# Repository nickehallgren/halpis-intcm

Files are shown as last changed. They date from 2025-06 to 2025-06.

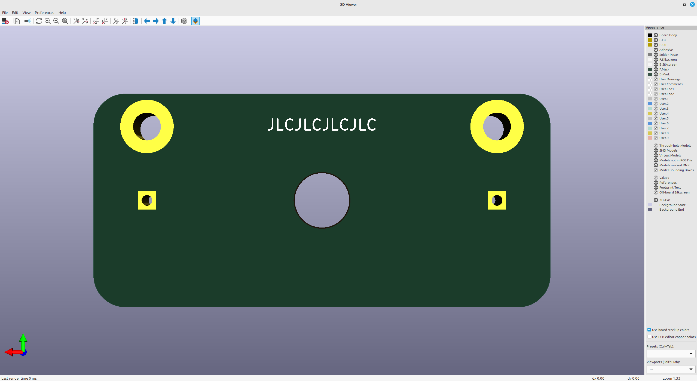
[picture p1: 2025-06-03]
hw/bp/images/2024_7_battery_connector_v1_1_back.png

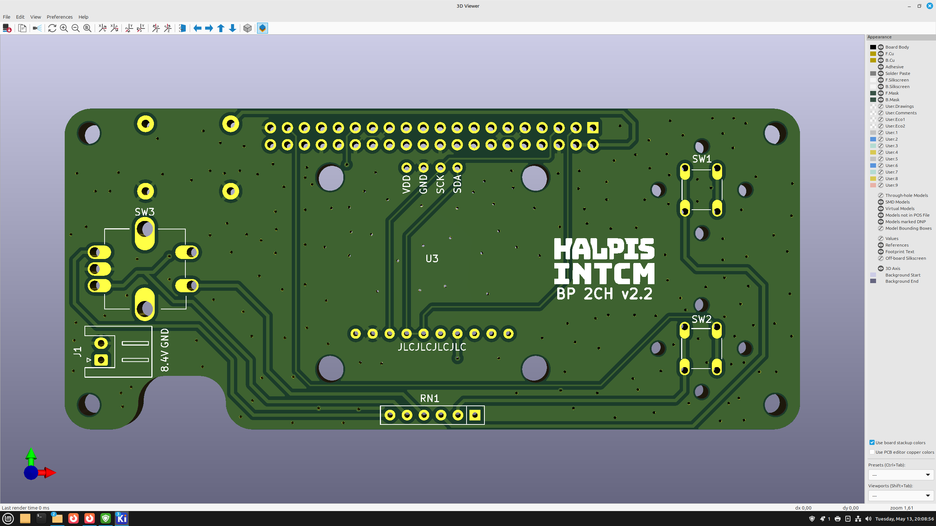
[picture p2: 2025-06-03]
hw/bp/images/2024_19_rpi3a_bp_v2_2_front.png

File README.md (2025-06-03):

HALPIS INTCM

A DIY Intercom System Built on Raspberry Pi, Custom Hardware, and Mumble

    ⚠️ Disclaimer
    This repository is for archival purposes only.
    I will not be updating the code or providing support.
    That said — feel free to fork it, explore it, and adapt it to your needs!

🎙️ Overview

HALPIS INTCM is a fully custom-built intercom system originally developed as a project at Arcada University of Applied Sciences. The project began over 6 years ago — [watch the original prototype](https://youtu.be/14hbYhLjQ8Y) — and has evolved through hundreds of hours of spare-time development.

At its core, HALPIS INTCM uses Raspberry Pi hardware with deeply integrated software built around Mumble, a low-latency, open-source voice chat system. It's designed to provide stable and clear communication in environments like workshops, multi-room setups, and media production spaces.

🔧 Features

    Custom-designed PCBs (Gerbers included)

    Ready for SMD component assembly

    3D-printable STL files for enclosures

    Raspberry Pi-based nodes for flexible deployment

    Integrated with Mumble for high-quality voice transmission

    90% of the software has been rewritten from scratch

📚 Background

The original version of HALPIS INTCM was successfully deployed in Arcada’s multi-camera workshops and served reliably for years. As time passed, both the software and hardware needed a full refresh.

This updated version is the result of:

    Rewriting nearly all the code (self-taught, so don’t expect perfection!)

    Learning KiCad and designing completely new PCBs

    Creating a more modular and maintainable system

    Spending many, many hours tinkering, testing, and refining

📦 What’s Included

    ✅ Full source code

    ✅ Hardware design (Gerbers, BOM)

    ✅ STL files for 3D-printed cases

    ✅ Configuration scripts and setup files

📺 Installation and setup Playlists on YouTube (Please watch the videos in sequence to fully understand the system before deciding whether it suits your needs.):

[Hardware playlist](https://www.youtube.com/playlist?list=PLlqbl5uwx39gumhSaHmBt5Q9jyUTHKmu8)

[Software playlist](https://www.youtube.com/playlist?list=PLlqbl5uwx39iHd4o0S4KNSksK1rH12pub)

This project is licensed under the MIT License — you are free to use, modify, and distribute it.

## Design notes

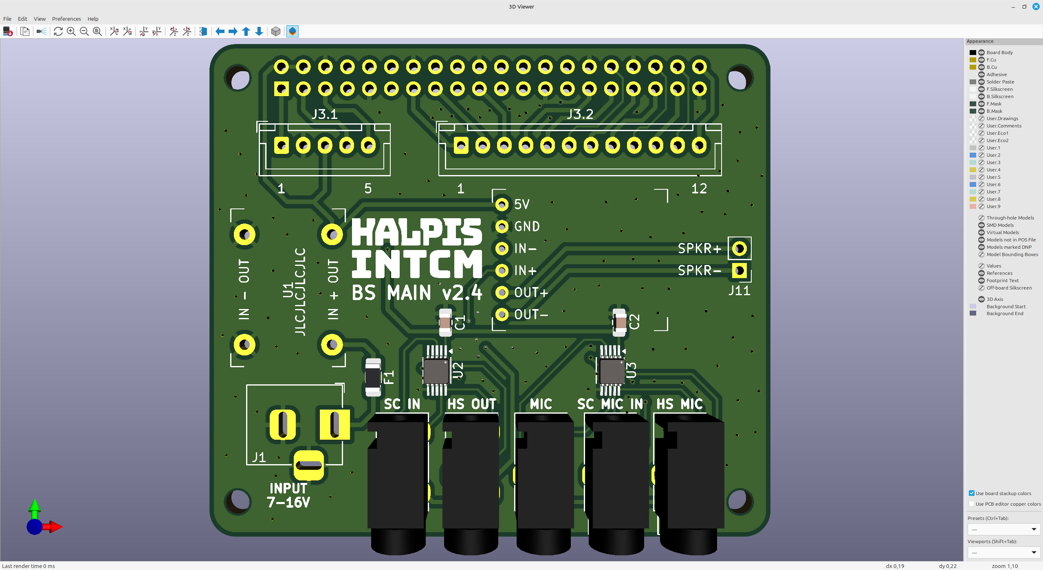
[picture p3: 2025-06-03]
hw/bs/images/2024_18_rpi3b_bs_v2_4_front.png

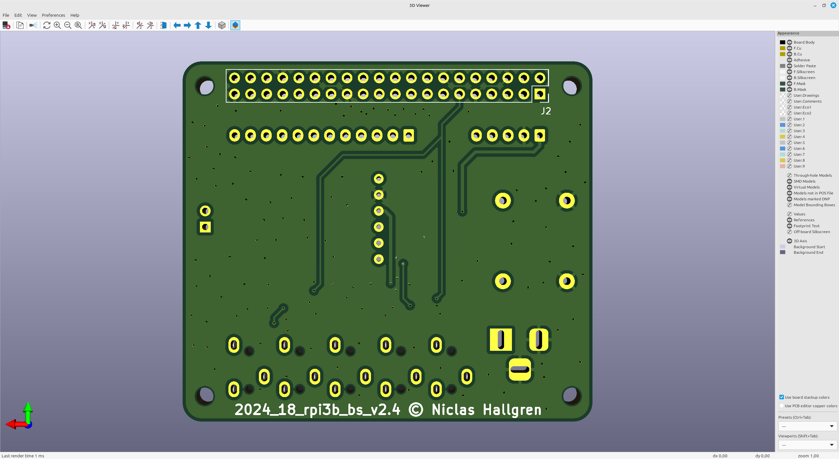
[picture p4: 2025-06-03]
hw/bs/images/2024_18_rpi3b_bs_v2_4_back.png

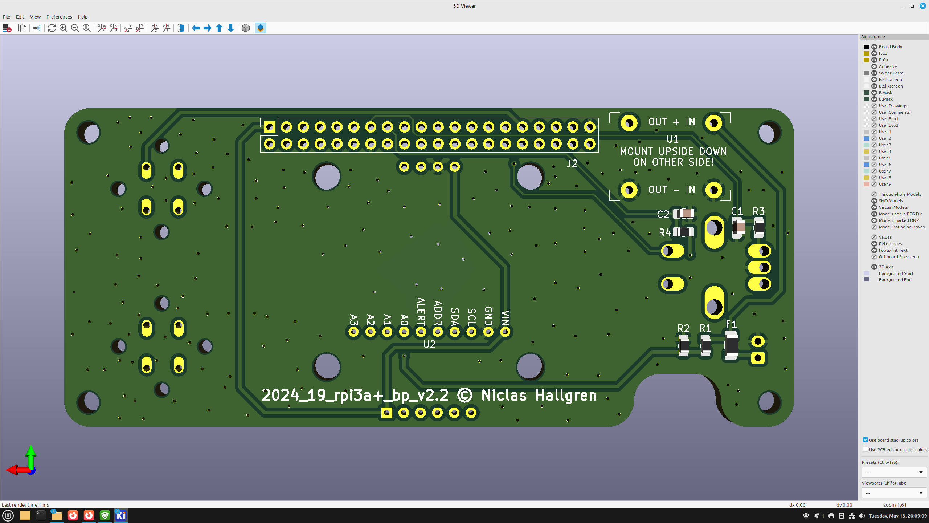
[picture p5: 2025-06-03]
hw/bp/images/2024_19_rpi3a_bp_v2_2_back.png

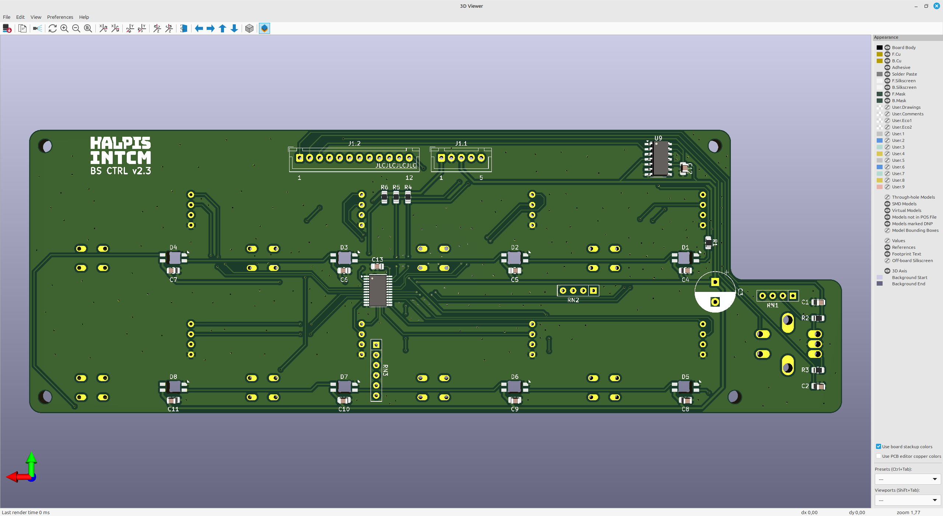
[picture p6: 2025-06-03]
hw/bs/images/2024_15_bs_control_v2.3_back.png

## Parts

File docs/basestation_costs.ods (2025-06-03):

Amount | Item | Use | Price | Buy size | Buy price | Link
1 | Step-down buck converter 5.3V | Main PCB | 1,47 | 1 | 1,47 | https://www.aliexpress.com/item/4001313603033.html
1 | 5.5x2.1mm DC-005 Black DC Power Jack | Main PCB | 0,202 | 10 | 2,02 | https://www.aliexpress.com/item/4001206395694.html
1 | 2x20 Pin Double Row Straight Female Pin Header 2.54mm | Main PCB | 0,131 | 10 | 1,31 | https://www.aliexpress.com/item/32854215610.html
4 | ID4.2xOD.7 11mm Nylon spacer | Main PCB | 0,2184 | 50 | 2,73 | https://www.aliexpress.com/item/1005007660225984.html
4 | M2.5 20mm round black screw | Main PCB | 0,2344 | 50 | 2,93 | https://www.aliexpress.com/item/32810852732.html
1 | Mini XH-M125 Mono Amplifier Board XPT8871 | Main PCB | 1,5 | 1 | 1,5 | https://www.aliexpress.com/item/1005006635033138.html
5 | 3.5mm Audio jack PJ320 3 Pin female | Main PCB | 0,375 | 10 | 0,75 | https://www.aliexpress.com/item/1005005886145686.html
2 | 5 pin JST XH 2.54mm Male connector | Main & Control PCB | 0,1112 | 50 | 2,78 | https://www.aliexpress.com/item/1005005530140025.html
2 | 12 pin JST XH 2.54mm Male connector | Main & Control PCB | 0,2036 | 50 | 5,09 | https://www.aliexpress.com/item/1005005530140025.html
1 | 40 Pin 1x40 Single Row Male | Main PCB | 0,184 | 10 | 1,84 | https://www.aliexpress.com/item/1005007324368709.htm
8 | 0.91 Inch I2C OLED Module 0.91" White 128X32 | Control PCB | 8,88 | 1 | 1,11 | https://www.aliexpress.com/item/32797462749.html
1 | 16V 1000uF capcitor | Control PCB | 0,126 | 20 | 2,52 | https://www.aliexpress.com/item/4000031065489.html
2 | 4pin DIP Network resistor array 10k | Control PCB | 0,154 | 10 | 0,77 | https://www.aliexpress.com/item/1005006523725090.html
1 | 6pin DIP Network resistor array 10k | Control PCB | 0,182 | 10 | 1,82 | https://www.aliexpress.com/item/1005006523725090.html
1 | Half 15mm encoder | Control PCB | 0,4895 | 20 | 9,79 | https://www.aliexpress.com/item/32868141761.html
8 | 6x6x6mm Waterproof Tact Switch | Control PCB | 0,784 | 20 | 1,96 | https://www.aliexpress.com/item/1005006804384250.html
1 | 5 pin 30cm Reverse direction JST XH 2.54 cable | Main to control PCB | 0,69 | 5 | 3,45 | https://www.aliexpress.com/item/1005005815261340.html
1 | 12 pin 30cm Reverse direction JST XH 2.54 cable | Main to control PCB | 0,806 | 5 | 4,03 | https://www.aliexpress.com/item/1005005815261340.html
1 | M3x16mm CS | Rack mount | 0,0576 | 50 | 2,88 | https://www.aliexpress.com/item/32968368588.html
1 | M3x3.8mm lock nut | Rack mount | 0,0548 | 50 | 2,74 | https://www.aliexpress.com/item/32988086058.html
1 | 4pin XLR male Neutrik NC4 MD-LX-B (headset) | Rack mount (right) | 6,6 | 1 | 6,6 | https://www.thomann.de/intl/neutrik_nc4_md_lx_b.htm
0 | alternative XLR male | Rack mount (right) | 0 | 1 | 0,77 | https://www.aliexpress.com/item/1005004216954405.html
1 | 3pin XLR female Neutrik NC3 MD-LX-B (mic) | Rack mount (left) | 4,66 | 1 | 4,66 | https://www.thomann.de/fi/neutrik_nc3m_dlx_b.htm
0 | alternative XLR female | Rack mount (left) | 0 | 1 | 0,56 | https://www.aliexpress.com/item/1005004216954405.html
4 | M3x10mm CS BLK | XLR Mount | 0,1944 | 50 | 2,43 | https://www.aliexpress.com/item/32968368588.html
4 | M3 Lock nut BLK | XLR Mount | 0,2192 | 50 | 2,74 | https://www.aliexpress.com/item/32988086058.html
1 | AIYIMA 2 Inch Full Range Speaker 4 Ohm 5W | Rack mount (right) | 4,515 | 2 | 9,03 | https://www.aliexpress.com/item/1005004143927520.html
4 | M4*8 self tapped screws | Rack mount (right) | 0,2552 | 50 | 3,19 | https://www.aliexpress.com/item/32963090335.html
4 | M2.5 nuts | Rack mount (right) | 0,2944 | 25 | 1,84 | https://www.aliexpress.com/item/1005001412230125.html
2 | zip ties
2 | 15cm female to female dupont wires | Rack mount (right) | 0,1 | 40 | 2 | https://www.aliexpress.com/item/1005006225046713.html
1 | 3.5mm Aux Audio Noise Filter | Rack mount (right) | 3,78 | 1 | 3,78 | https://www.aliexpress.com/item/1005007193543196.html
1 | 3.5mm 50cm Male to Male 90 deg Audio Cable 3 Pole | Main PCB | 0,63 | 1 | 0,63 | https://www.aliexpress.com/item/1005003175350504.html
5 | 3.5mm 15cm Male to Male 90 deg Audio Cable 3 Pole | Main PCB | 4,1 | 1 | 0,82 | https://www.aliexpress.com/item/1005002460582024.html
4 | M2.6x10 self-tapping pan head screw | Control PCB | 0,0948 | 100 | 2,37 | https://www.aliexpress.com/item/33043885403.html
4 | M3*8*1 Soft PVC Flat washer | Control PCB | 0,0796 | 100 | 1,99 | https://www.aliexpress.com/item/1005003697132040.html
1 | Vention USB black soundcard | Raspberry Pi | 6,99 | 1 | 6,99 | https://www.aliexpress.com/item/32838236733.html
1 | Cardioid Conference Microphone Gooseneck | Rack mount (left) | 27,69 | 1 | 27,69 | https://www.aliexpress.com/item/1005004230383012.html
1 | Raspberry Pi 3 Model B+ |  | 43,95 | 1 | 43,95 | https://www.raspberrystore.nl/PrestaShop/en/raspberry-pi-v3-b-2018/191-raspberry-pi-3-model-b-0713179640259.html
1 | Micro SD card 32GB (any fast 8GB+, will work) |  | 9,95 | 1 | 9,95 | https://www.raspberrystore.nl/PrestaShop/en/storage-sd-kaarten-en-ssd-s/594-micro-sd-kaart-32gb-van-raspberrypi-inclusief-raspberry-pi-os-met-desktop-pre-inst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
1 | Assembled control PCB (all smd soldered) |  | 8,18 | 5 | 40,9 | https://jlcpcb.com
1 | Assembled main PCB (all smd soldered) |  | 5,502 | 5 | 27,51 | https://jlcpcb.com
 |  | Total price (shipping excluded) | 144,6381 |  |  | Prices updated 21 April 2025
 |  | enclosure pla 250g (6€)

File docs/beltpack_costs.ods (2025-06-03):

Amount | Item | Use | Price | Buy size | Buy price | Link
2 | M2.5x8 Black Nylon CS | Mount OLED display to PCB | 0,104 | 20 | 1,04 | https://www.aliexpress.com/item/1005002287052957.html
4 | M2.5 Black Nylon nuts | Mount OLED display to PCB | 0,208 | 50 | 2,6 | https://www.aliexpress.com/item/32874859068.html
2 | M2.6x10 self-tapping pan head screw | Pi foot | 0,0474 | 100 | 2,37 | https://www.aliexpress.com/item/33043885403.html
1 | 2x20 pin 2.54mm Double Row Ang. Female Header | Main PCB | 0,389 | 10 | 3,89 | https://www.aliexpress.com/item/1005006493171435.html
1 | 1,3" White 4pin i2c OLED display | Main PCB | 2,33 | 1 | 2,33 | https://www.aliexpress.com/item/4001145494936.html
1 | Step-down buck converter 5.3V | Main PCB | 1,47 | 1 | 1,47 | https://www.aliexpress.com/item/4001313603033.html
1 | Half 15mm encoder | Main PCB | 0,4895 | 20 | 9,79 | https://www.aliexpress.com/item/32868141761.html
1 | 2pin JST XH 2.54 Side entry connector | Main PCB | 0,028 | 100 | 2,8 | https://www.aliexpress.com/item/1005004985397880.html
1 | 6pin DIP Network resistor array 10k | Main PCB | 0,071 | 10 | 0,71 | https://www.aliexpress.com/item/1005006523725090.html
1 | ADS1115 i2c ADC module (small!!) | Main PCB | 1,57 | 1 | 1,57 | https://www.aliexpress.com/item/32822725649.html
2 | 6x6x6mm Waterproof Tact Switch | Main PCB | 0,203 | 20 | 2,03 | https://www.aliexpress.com/item/1005006804384250.html
2 | M4x8mm CS BLK | Belt Clip | 0,376 | 10 | 1,88 | https://www.aliexpress.com/item/32968368588.html
2 | M4 (height 4.8mm) Lock nut BLK | Belt Clip | 0,1148 | 50 | 2,87 | https://www.aliexpress.com/item/32988086058.html
2 | M3x10mm CS BLK | XLR Mount | 0,0972 | 50 | 2,43 | https://www.aliexpress.com/item/32968368588.html
2 | M3 Lock nut BLK | XLR Mount | 0,1096 | 50 | 2,74 | https://www.aliexpress.com/item/32988086058.html
1 | Neutrik NC4 MD-LX-B (4 pin male, beltpack) | XLR | 6,6 | 1 | 6,6 | https://www.thomann.de/intl/neutrik_nc4_md_lx_b.htm
0 | alternative XLR male | XLR | 0 | 1 | 0,77 | https://www.aliexpress.com/item/1005004216954405.html
4 | M3x16mm CS | Top cover | 0,2304 | 50 | 2,88 | https://www.aliexpress.com/item/32968368588.html
4 | M3x2.4mm nut | Top cover | 0,3184 | 25 | 1,99 | https://www.aliexpress.com/item/1005001412230125.html
4 | M3x3.8mm lock nut | Attach battery to main (print) | 0,2192 | 50 | 2,74 | https://www.aliexpress.com/item/32988086058.html
4 | M3x30mm | Attach battery to main (print) | 0,304 | 50 | 3,8 | https://www.aliexpress.com/item/32968368588.html
1 | 30cm 3/3 pole two angled 3.5mm cable | Sound card, cut in half | 0,95 | 1 | 0,95 | https://www.aliexpress.com/item/1005002460582024.html
1 | 10cm 2pin JST XH 2.54mm | Main PCB | 0,4 | 5 | 2 | https://www.aliexpress.com/item/1005007079265201.html
2 | 2.0mm Bullet Banana Plug (battery connector) | Battery PCB | 0,8 | 10 | 4 | https://www.aliexpress.com/item/4000439855711.html
1 | Spring 1x7-14x12-5mm | Battery PCB | 0,556 | 10 | 5,56 | https://www.aliexpress.com/item/1005003508713861.html
1 | Vention USB black soundcard | Raspberry Pi | 6,99 | 1 | 6,99 | https://www.aliexpress.com/item/32838236733.html
1 | 180 Degree USB 2.0 Down | Raspberry Pi | 1,56 | 1 | 1,56 | https://www.aliexpress.com/item/1005004208654482.html
1 | Raspberry Pi 3 Model A+ |  | 25,95 | 1 | 25,95 | https://www.raspberrystore.nl/PrestaShop/en/raspberry-pi-v3-b-2018/211-raspberry-pi-3-model-a-0652508442181.html
1 | Micro SD card 32GB (any fast 8GB+, will work) |  | 9,95 | 1 | 9,95 | https://www.raspberrystore.nl/PrestaShop/en/storage-sd-kaarten-en-ssd-s/594-micro-sd-kaart-32gb-van-raspberrypi-inclusief-raspberry-pi-os-met-desktop-pre-inst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
1 | Assembled main PCB (all smd soldered) |  | 2,105 | 10 | 21,05 | https://jlcpcb.com
1 | Battery PCB |  | 0,571 | 10 | 5,71 | https://jlcpcb.com
1 | NP-F570 Rechargeable Battery |  | 55 | 1 | 55 | https://www.thomann.de/intl/blackmagic_design_np_f570_rechargeable_battery.htm
1 | Headset Superlux HMC 660 X (cut the connectors) |  | 45 | 1 | 45 | https://www.thomann.de/intl/superlux_hmc_660_x.htm
1 | Neutrik NC4 FXX-B (4 pin female for headset) |  | 6,2 | 1 | 6,2 | https://www.thomann.de/fi/neutrik_nc4_fxx_b.htm
 |  | Price per beltpack (shipping excluded) | 171,3115 |  |  | Prices updated 10 April 2025
 |  | + enclosure ~180g PLA (4,30€)

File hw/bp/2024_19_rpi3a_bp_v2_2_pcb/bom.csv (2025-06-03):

Designator | Footprint | Quantity | Value | LCSC Part #
C1, C2 | 0805 | 2 | 10nF | C1710
F1 | 1206 | 1 | 1.5A | C553929
R1 | 0805 | 1 | 680K | C17797
R2 | 0805 | 1 | 330K | C17629
R3, R4 | 0805 | 2 | 10K | C17414

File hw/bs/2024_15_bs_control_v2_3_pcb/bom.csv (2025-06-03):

Designator | Footprint | Quantity | Value | LCSC Part #
C1, C10, C11, C2, C4, C5, C6, C7, C8, C9 | 0805 | 10 | 10nF | C1710
C12 | 0805 | 1 | 100nF | C1711
C13 | 0805 | 1 | 10uF | C1713
D1, D2, D3, D4, D5, D6, D7, D8 | SK6812 MINI-E MX | 8 | SK6812MINI-E | C5149201
R1 | 0805 | 1 | 430R | C42000
R2, R3, R4, R5, R6 | 0805 | 5 | 10K | C17414
U10 | TSSOP-24_4.4x7.8mm_P0.65mm | 1 | TCA9548APWR | C130026
U9 | SOIC-14_3.9x8.7mm_P1.27mm | 1 | SN74AHCT125DR | C155176

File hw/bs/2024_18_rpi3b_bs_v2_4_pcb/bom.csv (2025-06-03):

Designator | Footprint | Quantity | Value | LCSC Part #
C1, C2 | 0805 | 2 | 0,1uF | C1711
F1 | 1206 | 1 | 1.5A | C7542963
U2 | VSSOP-10_3x3mm_P0.5mm | 1 | SC | C105181
U3 | VSSOP-10_3x3mm_P0.5mm | 1 | MIC | C105181

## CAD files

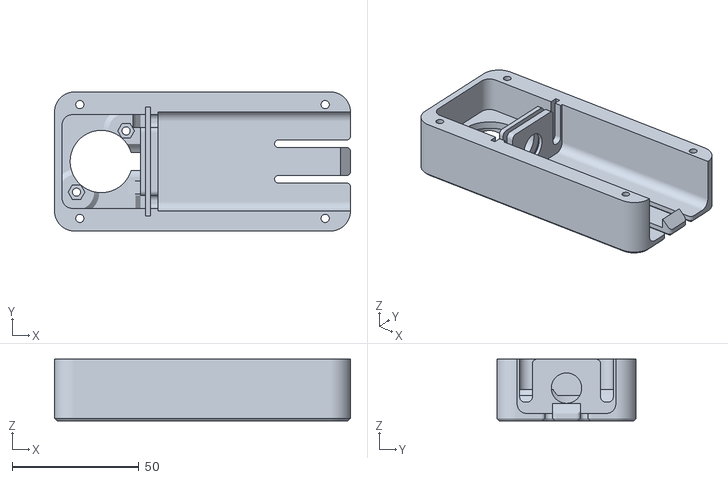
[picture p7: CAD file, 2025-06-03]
stl/bp/battery.stl
117.0 x 55.0 x 24.5

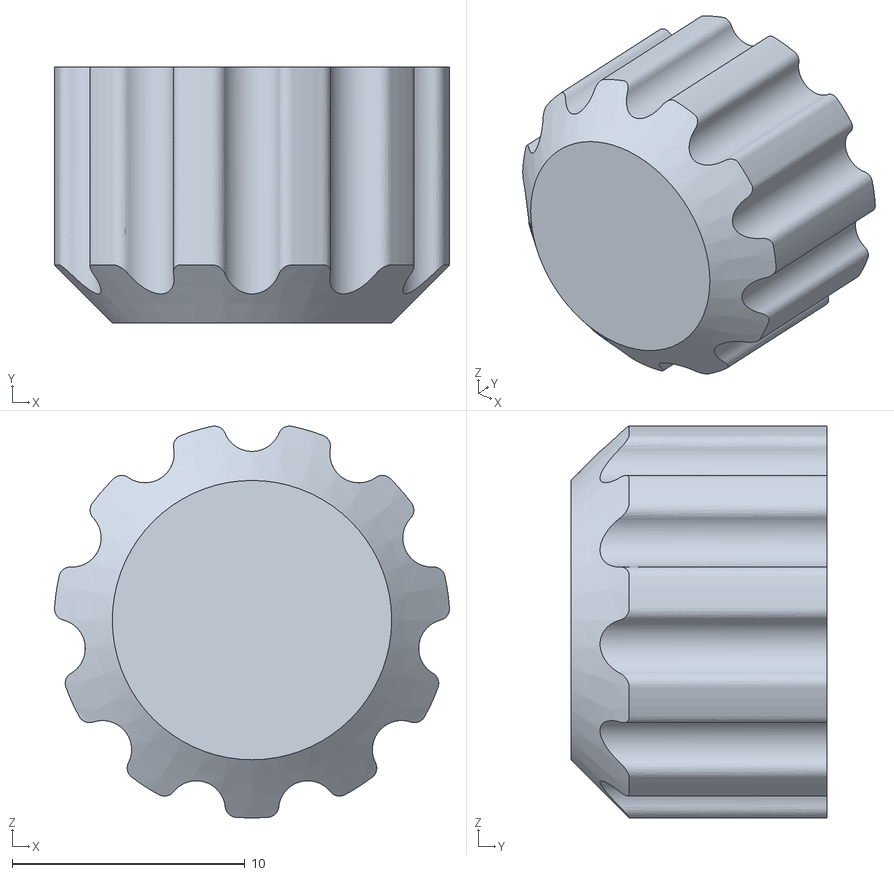
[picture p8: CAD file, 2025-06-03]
stl/bs_v2_3/encoder_hat_v2.stl
17.0 x 11.0 x 16.8

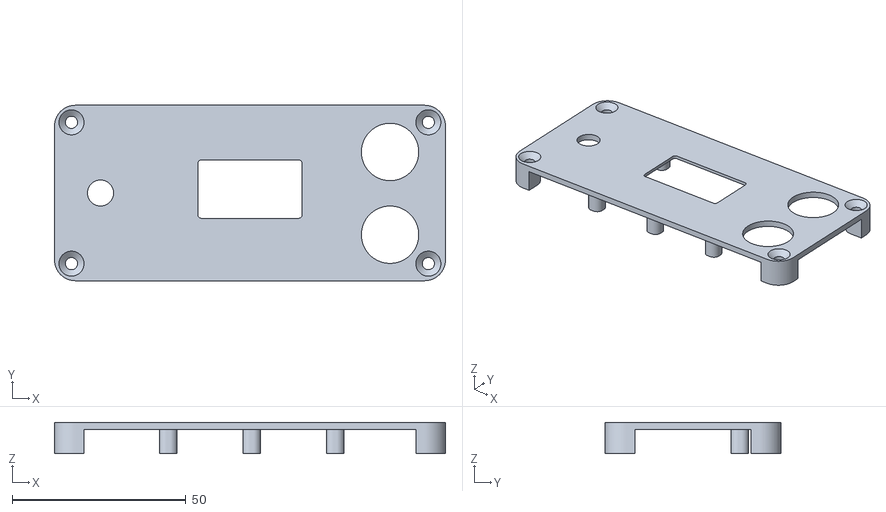
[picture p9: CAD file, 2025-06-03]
stl/bp/top_ext_btn.stl
112.5 x 50.5 x 9.00

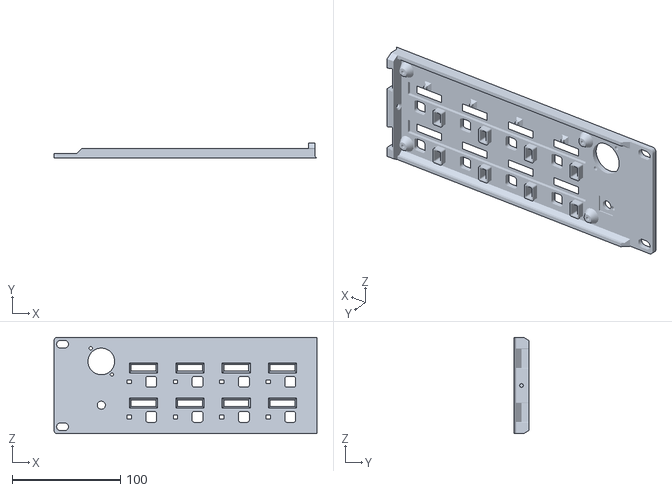
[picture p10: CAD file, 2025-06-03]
stl/bs_v2_3/left_v2_7.stl
243.0 x 14.0 x 89.0

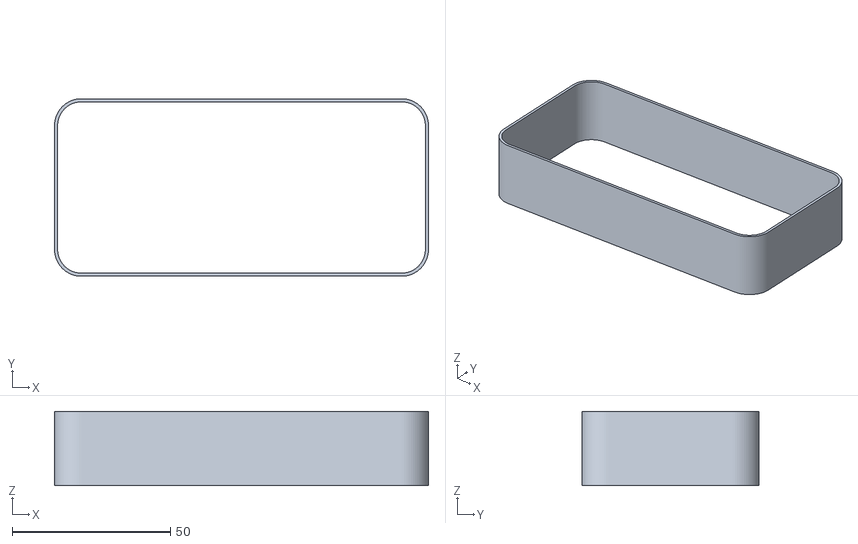
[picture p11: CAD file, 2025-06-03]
stl/bp/battery_fuzz.stl
118.0 x 56.0 x 23.5

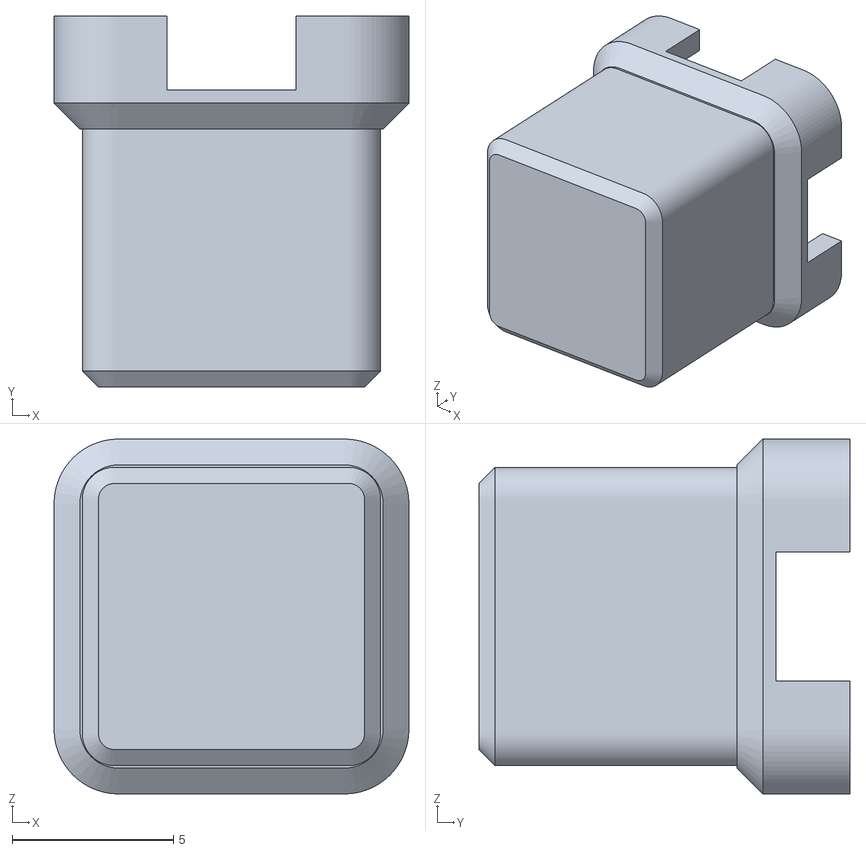
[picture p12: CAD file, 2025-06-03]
stl/bs_v2_3/ptt_square_button_v2.stl
11.0 x 11.5 x 11.0

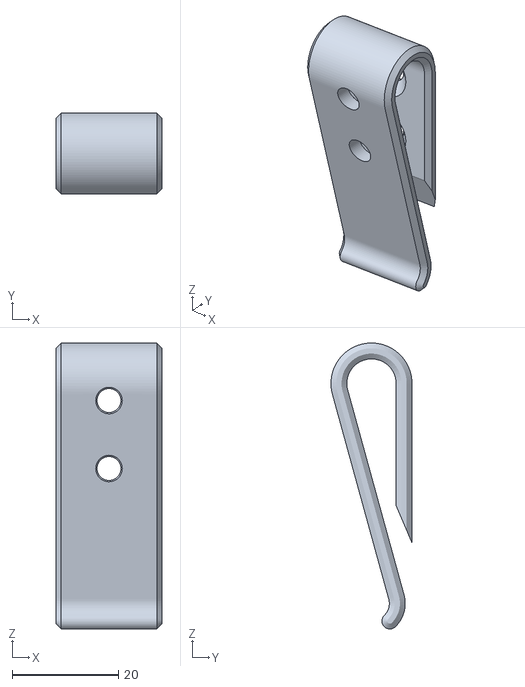
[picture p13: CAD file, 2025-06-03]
stl/bp/belt_clip.stl
20.0 x 15.3 x 53.9

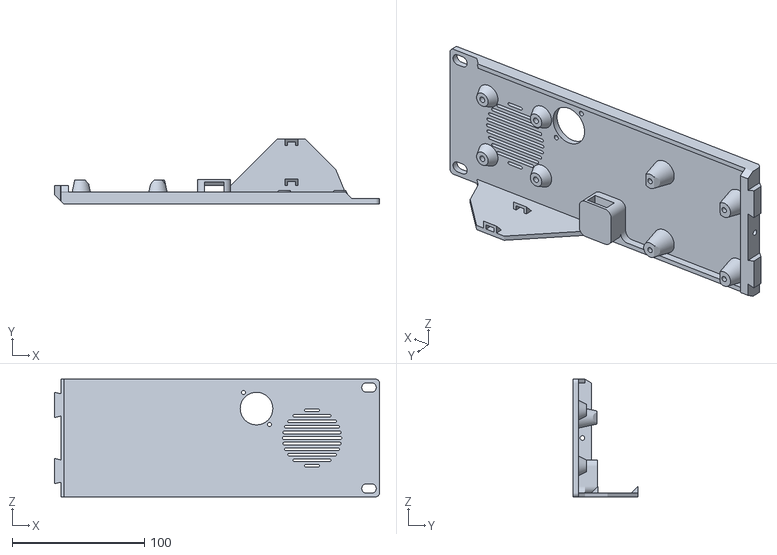
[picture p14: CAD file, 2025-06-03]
stl/bs_v2_3/right_v2_7.stl
245.8 x 49.0 x 89.0

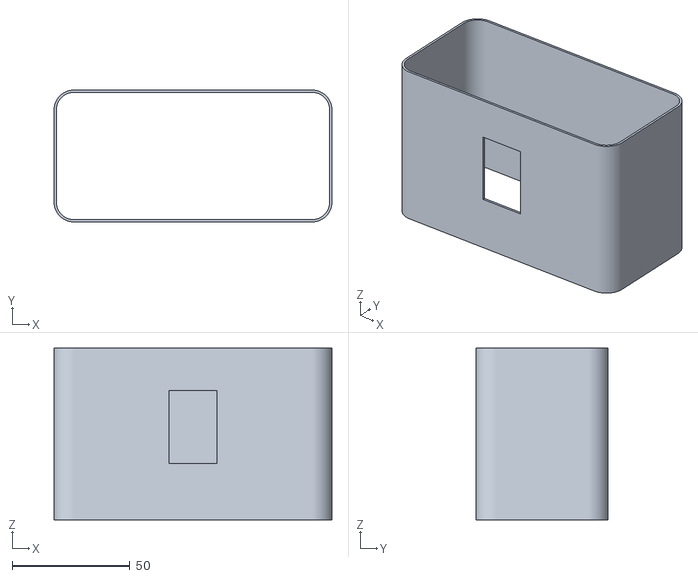
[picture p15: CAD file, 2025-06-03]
stl/bp/intcm_fuzz.stl
118.0 x 56.0 x 73.0

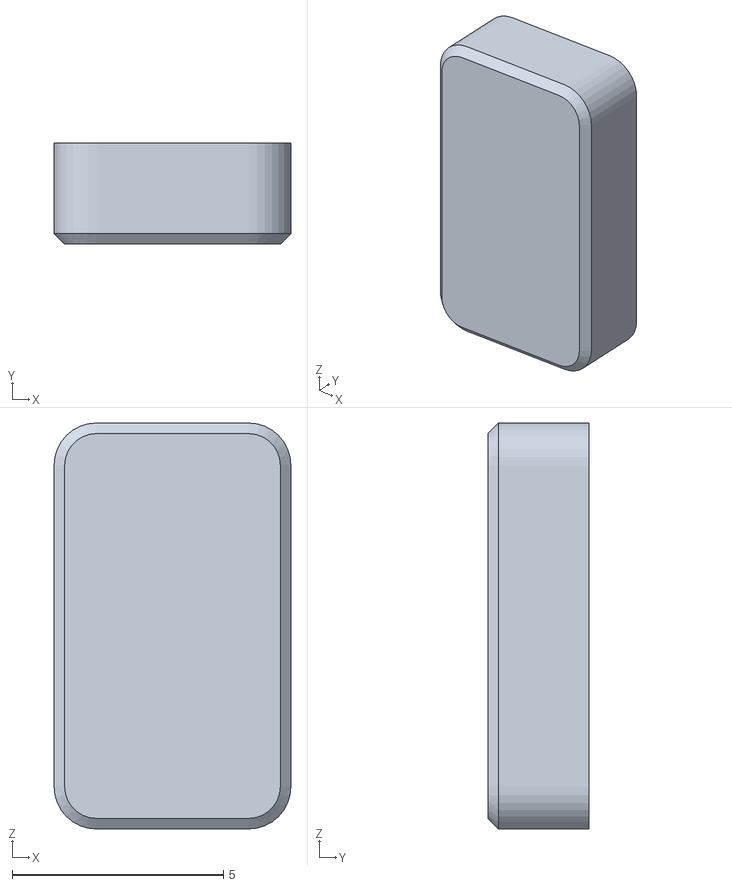
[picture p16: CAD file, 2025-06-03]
stl/bs_v2_3/neopixel_window.stl
5.60 x 2.40 x 9.60

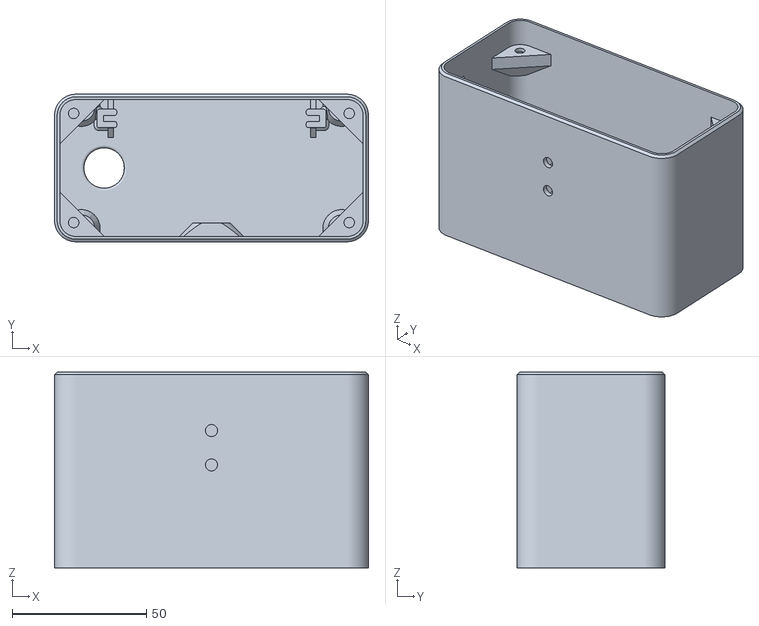
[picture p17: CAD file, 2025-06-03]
stl/bp/intcm.stl
117.0 x 55.0 x 73.0

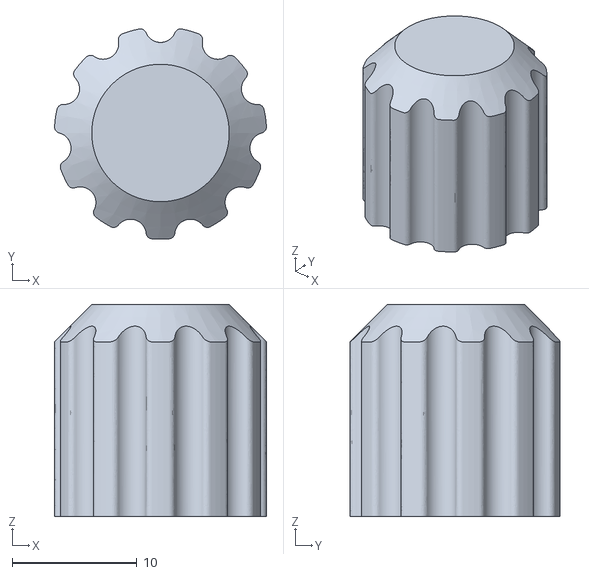
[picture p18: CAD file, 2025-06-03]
stl/bp/encoder_hat.stl
17.0 x 16.8 x 17.0

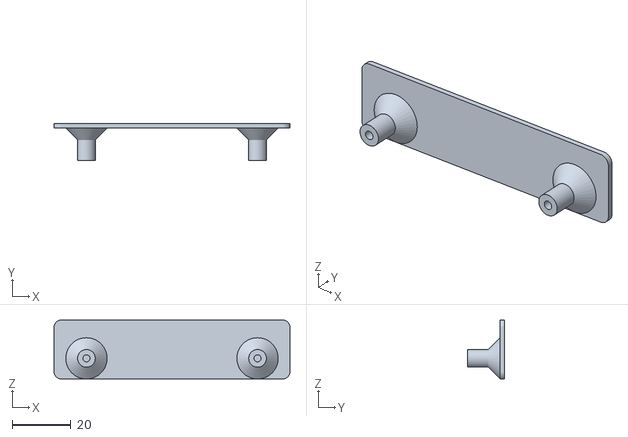
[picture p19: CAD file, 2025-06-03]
stl/bp/pi_foot.stl
80.0 x 12.5 x 20.0

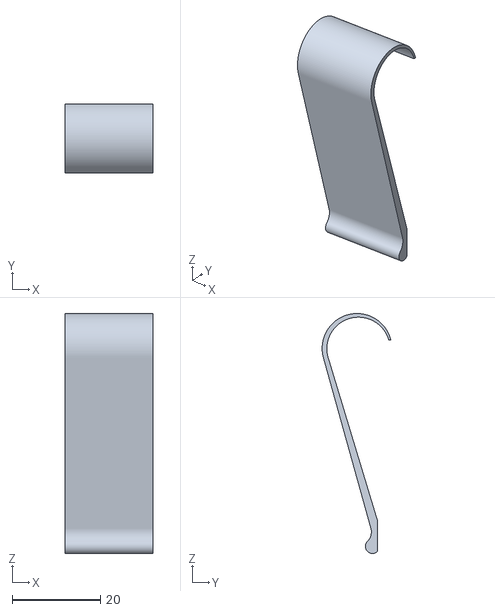
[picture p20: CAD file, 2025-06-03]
stl/bp/belt_clip_fuzz.stl
20.0 x 15.5 x 54.2

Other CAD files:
stl/bp/button_foot.stl
stl/bp/top_v2.stl

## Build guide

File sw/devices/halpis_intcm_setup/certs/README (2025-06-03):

This folder must contain you generated Mumble certificates CAM1, CAM2, etc

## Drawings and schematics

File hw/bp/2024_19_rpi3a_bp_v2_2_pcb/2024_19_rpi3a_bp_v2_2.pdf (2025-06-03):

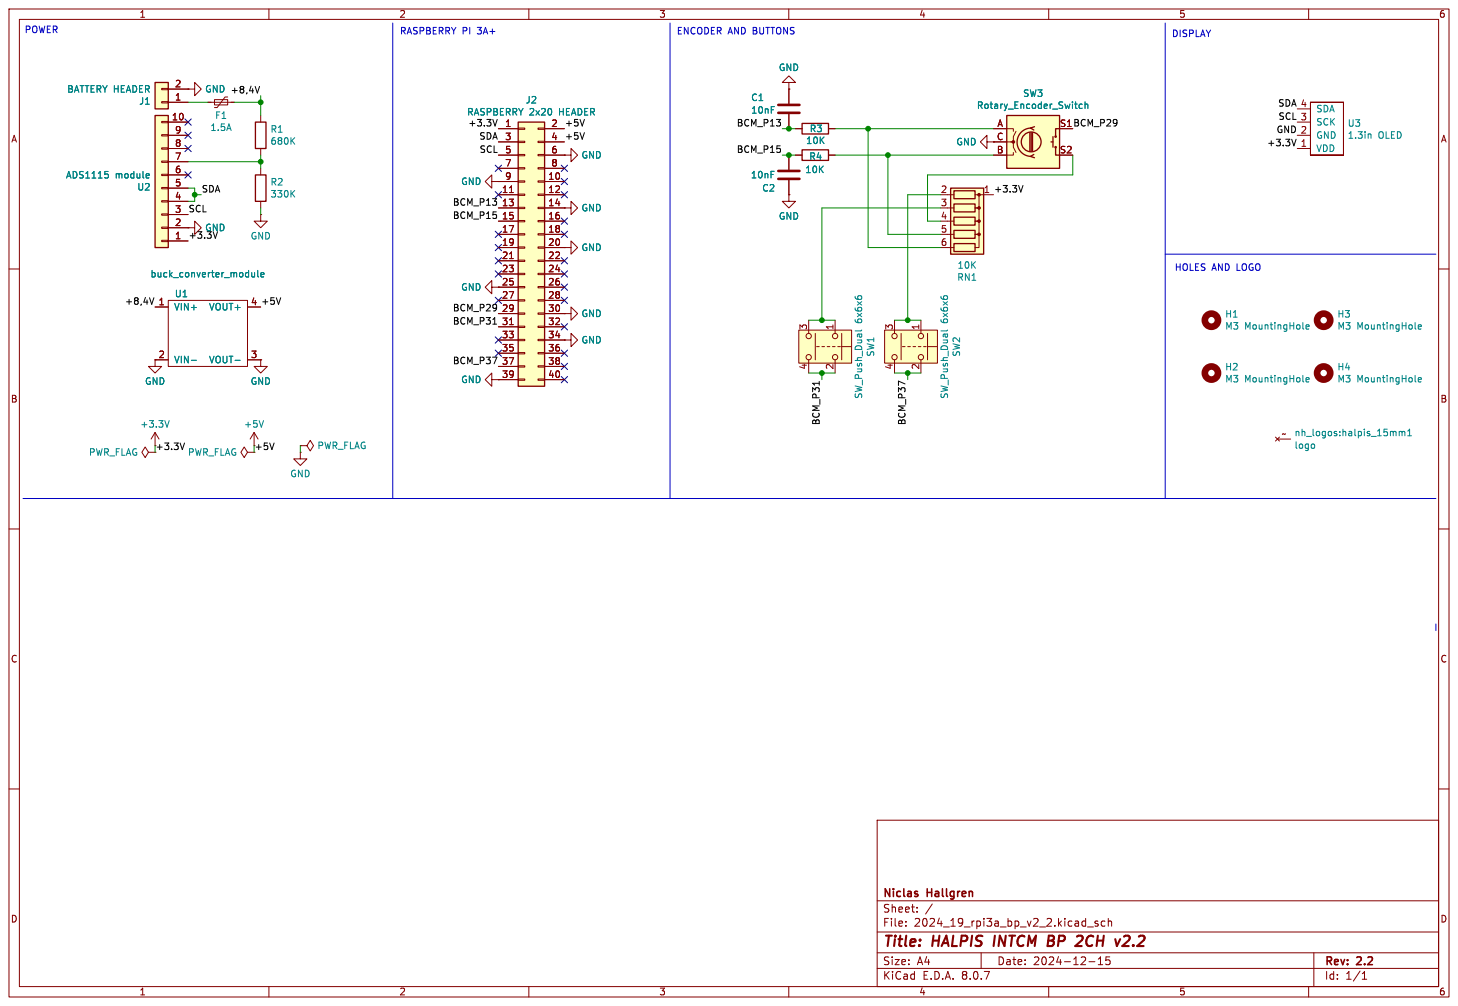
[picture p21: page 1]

Id: 1/1 Title: HALPIS INTCM BP 2CH v2.2

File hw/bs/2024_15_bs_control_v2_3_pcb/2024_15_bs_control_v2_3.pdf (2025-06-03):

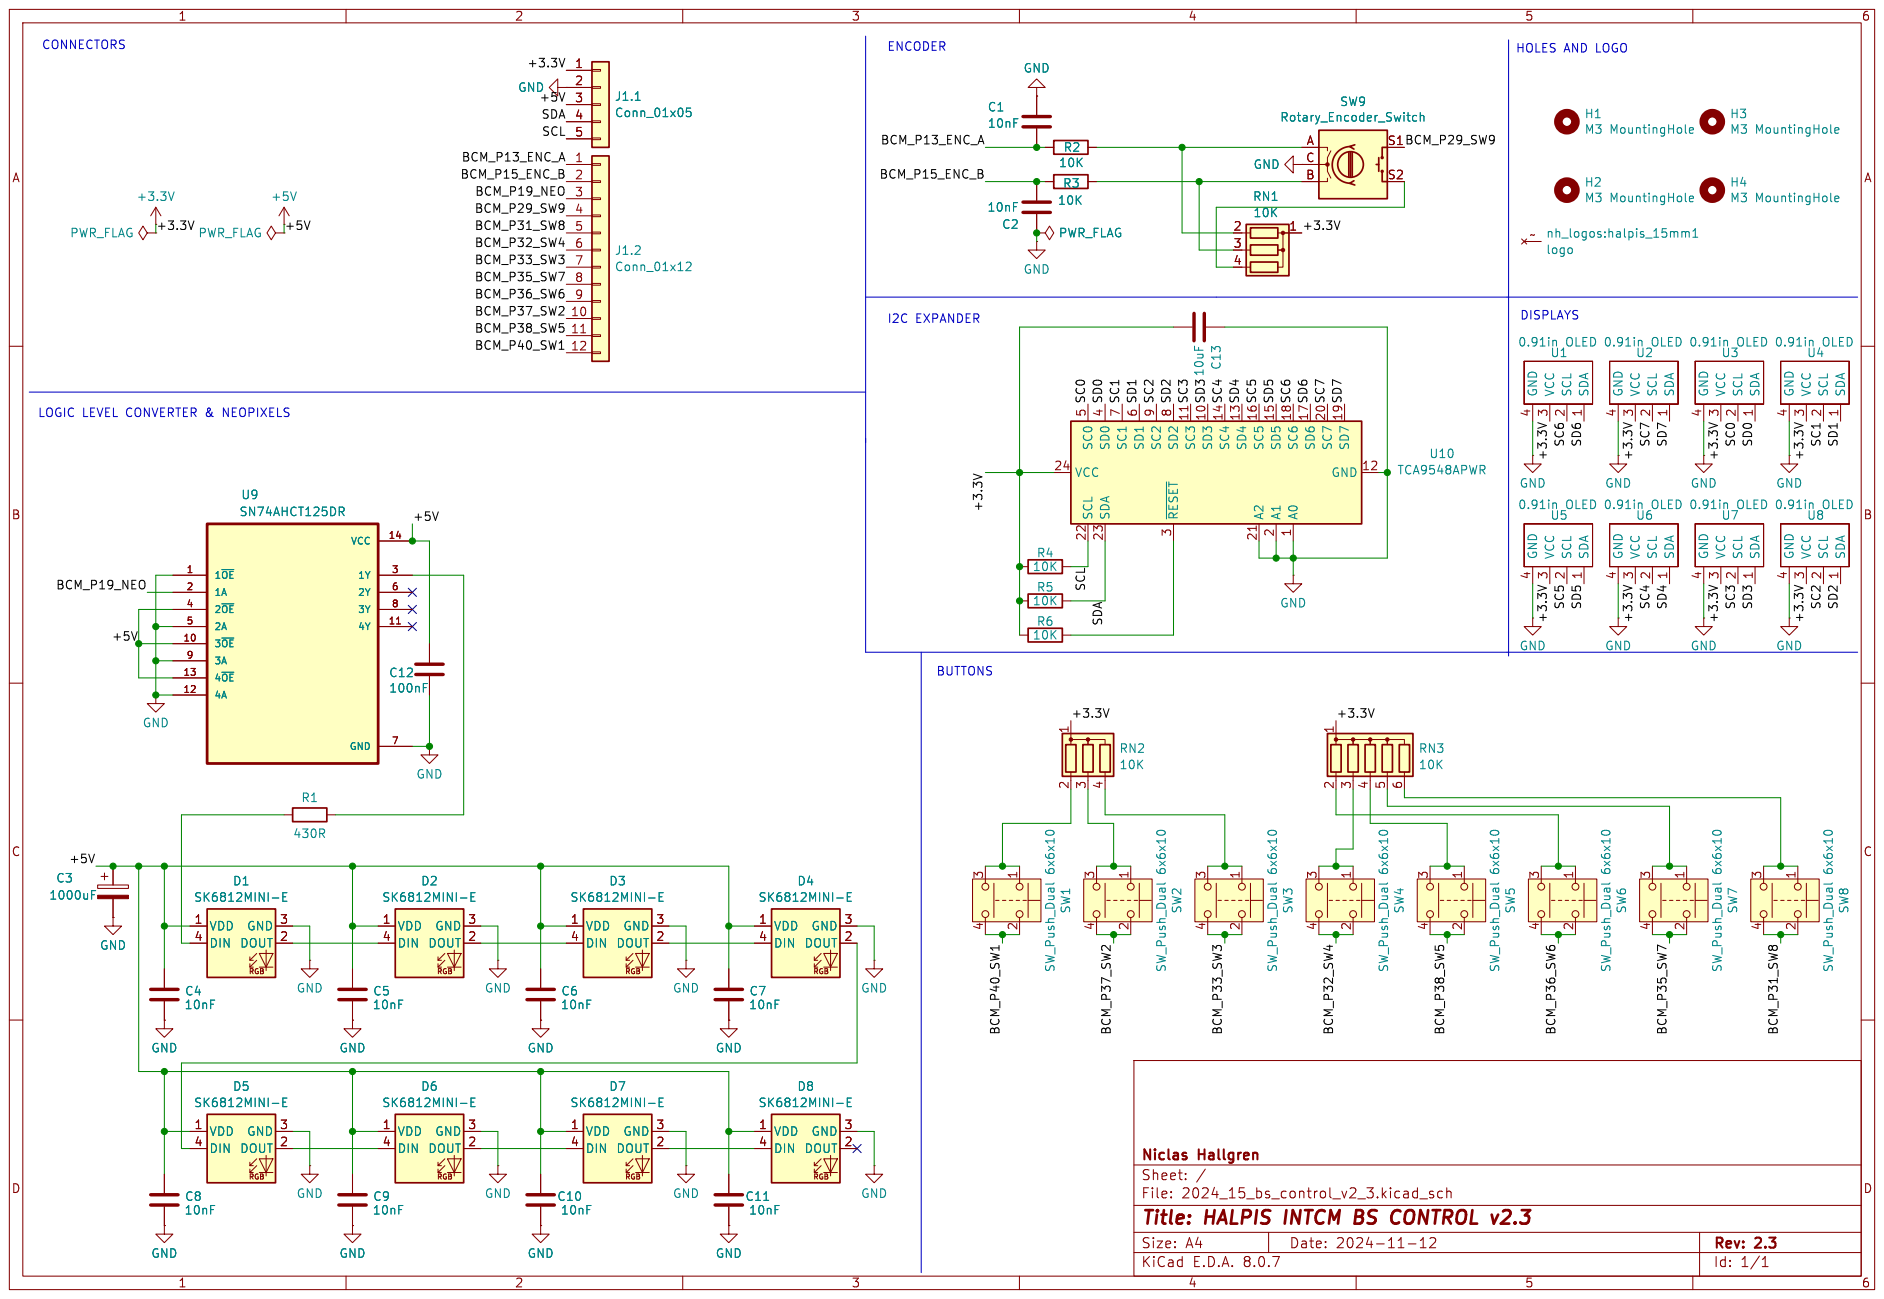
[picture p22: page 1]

LOGIC LEVEL CONVERTER & NEOPIXELS

2 SC7 20 A2 21 SCL 22 SDA 23 VCC 24 ~{RESET} 3 SD0

Id: 1/1 Title: HALPIS INTCM BS CONTROL v2.3

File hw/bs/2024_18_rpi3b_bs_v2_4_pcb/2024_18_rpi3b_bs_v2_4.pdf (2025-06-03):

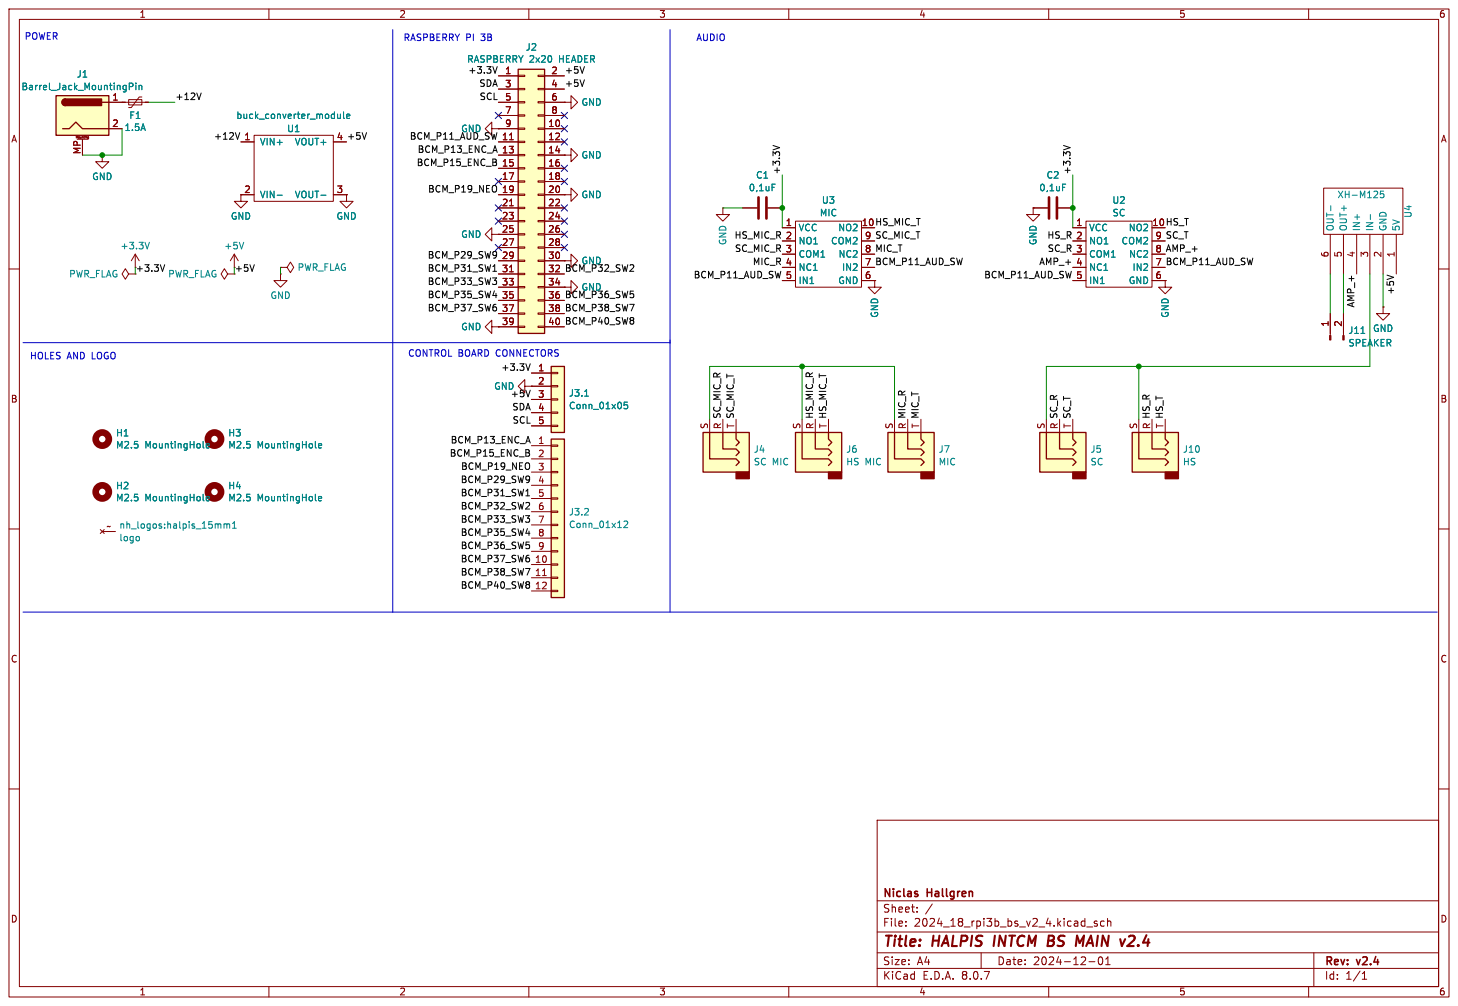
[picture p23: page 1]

Id: 1/1 Title: HALPIS INTCM BS MAIN v2.4

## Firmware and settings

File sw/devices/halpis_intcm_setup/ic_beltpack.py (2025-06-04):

# HALPIS Intercom Beltpack for Raspberry Pi
# Copyright (c) 2024, Niclas Hallgren
# All rights reserved.
#
# This source code is licensed under the MIT license found in the
# LICENSE file in the root directory of this source tree.

import fnmatch
from time import time, sleep
import copy
import os
import re
import inspect
import socket
import sys
import ssl
import signal
import logging
import subprocess
from typing import Dict, List, Tuple
from threading import Thread
import errno
import pyautogui
import RPi.GPIO as GPIO
import paho.mqtt.client as mqtt
from paho.mqtt.client import (
    Client,
    MQTTMessage,
    DisconnectFlags,
    ReasonCode,
    Properties
)
from typing import List
from ic import Intercom
from ic_ads1115 import IntercomADS1115
from ic_config import IntercomConfig
from ic_display import IntercomDisplay
from ic_button import IntercomButton
from ic_encoder import IntercomEncoder
from ic_menu_bp import menu


def is_mumble_window_visible():
    try:
        result = subprocess.run(
            ["xdotool", "search", "--onlyvisible", "--name", "Mumble"],
            stdout=subprocess.DEVNULL,
            stderr=subprocess.DEVNULL,
            check=False,
        )
        return result.returncode == 0
    except FileNotFoundError:
        logger.critical(f"xdotool is not installed!")
        raise RuntimeError("xdotool is not installed")


def wait_for_mumble(timeout=60, interval=1):
    logger.debug(f"Waiting for Mumble window to appear...")
    start_time = time()
    while time() - start_time < timeout:
        if is_mumble_window_visible():
            logger.debug(f"Mumble window detected.")
            return True
        render_text_lines(
            0,
            [
                "WAITING",
                "FOR MUMBLE",
                "TO START..."
            ]
        )
        sleep(interval)
    logger.warning(f"Timeout: Mumble window not found.")
    return False

def mqtt_publish(topic: str, message: str) -> None:
    """
    Publish a message to an MQTT topic.

    Args:
        topic (str): The MQTT topic to publish to.
        message (str): The message to publish.
    """
    try:
        client.publish(topic, message, qos=1, retain=True)
    except ValueError as e:
        logger.warning(f"MQTT Publish ValueError occurred: {e}")
    except Exception as e:
        logger.warning(f"MQTT Publish An unexpected error occurred: {e}")


def mqtt_subscribe(topic: str) -> None:
    """
    Subscribe to an MQTT topic.

    Args:
        topic (str): The MQTT topic to subscribe to.
    """
    try:
        client.subscribe(topic, qos=1)
    except ValueError as e:
        logger.warning(f"MQTT Subscribe ValueError occurred: {e}")
    except Exception as e:
        logger.warning(f"MQTT Subscribe An unexpected error occurred: {e}")


def connect_mqtt() -> None:
    """
    Try to connect to MQTT
    """
    try:
        client.connect(intercom.mqtt_server, intercom.mqtt_port,
                       intercom.mqtt_keepalive)
    except ConnectionResetError as e:
        logger.warning(f"MQTT ConnectionResetError occurred: {e}")
        render_text_lines(
            0,
            [
                intercom.host_name,
                intercom.device_ip,
                intercom.mqtt_status_codes[3]
            ]
        )
        client.loop_stop()
        return
    except ConnectionRefusedError as e:
        logger.warning(f"MQTT ConnectionRefusedError occurred: {e}")
        render_text_lines(
            0,
            [
                intercom.host_name,
                intercom.device_ip,
                intercom.mqtt_status_codes[3]
            ]
        )
        client.loop_stop()
        return
    except socket.gaierror as e:
        logger.warning(
            f"MQTT Server not found (socket.gaierror) occurred: {e}")
        render_text_lines(
            0,
            [
                intercom.host_name,
                intercom.device_ip,
                intercom.mqtt_status_codes[98]
            ]
        )
        client.loop_stop()
        return
    except socket.timeout as e:
        logger.warning(f"MQTT Timeout occurred: {e}")
        render_text_lines(
            0,
            [
                intercom.host_name,
                intercom.device_ip,
                intercom.mqtt_status_codes[99]
            ]
        )
        client.loop_stop()
        return
    except ssl.SSLCertVerificationError as e:
        logger.warning(f"MQTT SSL Certification Error occurred: {e}")
        render_text_lines(
            0,
            [
                intercom.host_name,
                intercom.device_ip,
                "INVALID CERT"
            ]
        )
        client.loop_stop()
        return
    except OSError as e:
      if e.errno in {errno.EHOSTUNREACH, errno.ENETUNREACH, errno.ECONNABORTED}:
        logger.warning(f"MQTT network unreachable or host unreachable: {e}")
        render_text_lines(
            0,
            [
                intercom.host_name,
                intercom.device_ip,
                intercom.mqtt_status_codes[98]
            ]
        )
        client.loop_stop()
        return
    except Exception as e:
        logger.warning(f"MQTT Unknown Error occurred: {e}")
        render_text_lines(
            0,
            [
                intercom.host_name,
                intercom.device_ip,
                "UNKNOWN ERR"
            ]
        )
        client.loop_stop()
        return
    client.loop_start()


def on_connect(client: Client,
    userdata: None,
    flags: any,
    reason_code: any,
    properties: any,
) -> None:
    """
    MQTT connect, publish device information and subscribe to device 
    settings.
    
    Args:
        client (Client): The MQTT client instance.
        userdata (None): User-defined data of any type.
        flags (any): Response flags sent by the broker.
        reason_code (any): The connection result.
        properties (any): The properties associated with the connection.
    """
    if reason_code.is_failure:
        client.connected_flag = False
        if 'identifier rejected' in str(reason_code).lower():
            logger.warning(
                f"MQTT error: {str(reason_code).lower()}")
            render_text_lines(
                0,
                [
                    intercom.host_name,
                    intercom.device_ip,
                    intercom.mqtt_status_codes[2]
                ]
            )
        if 'broker unavailable' in str(reason_code).lower():
            logger.warning(
                f"MQTT error: {str(reason_code).lower()}")
            render_text_lines(
                0,
                [
                    intercom.host_name,
                    intercom.device_ip,
                    intercom.mqtt_status_codes[3]
                ]
            )
        if 'bad user name' in str(reason_code).lower():
            logger.warning(
                f"MQTT error: {str(reason_code).lower()}")
            render_text_lines(
                0,
                [
                    intercom.host_name,
                    intercom.device_ip,
                    intercom.mqtt_status_codes[4]
                ]
            )
        if 'not authorized' in str(reason_code).lower():
            logger.warning(
                f"MQTT error: {str(reason_code).lower()}")
            render_text_lines(
                0,
                [
                    intercom.host_name,
                    intercom.device_ip,
                    intercom.mqtt_status_codes[5]
                ]
            )
    else:
        logger.debug("MQTT connected")
        render_text_lines(
            0,
            [
                intercom.host_name,
                intercom.device_ip,
                intercom.mqtt_status_codes[0]
            ]
        )
        intercom.system_control = True
        client.connected_flag = True
    mqtt_publish(intercom.mqtt_prefix + "status/" +
                 intercom.host_name + "/state", "online")
    mqtt_publish(intercom.mqtt_prefix + "status/" +
                 intercom.host_name + "/device_channels",
                 intercom.channel_count)
    mqtt_publish(intercom.mqtt_prefix + "status/" +
                 intercom.host_name + "/device_type",
                 intercom.device_type)
    mqtt_publish(intercom.mqtt_prefix + "status/" +
                 intercom.host_name + "/allow_mic_level_change",
                 str(int(intercom.allow_mic_level_change)))
    mqtt_publish(intercom.mqtt_prefix + "status/" +
                 intercom.host_name + "/hs_audio_level",
                 intercom.get_audio_level())
    mqtt_publish(intercom.mqtt_prefix + "status/" +
                 intercom.host_name + "/mic_level",
                 intercom.get_mic_level())
    mqtt_publish(intercom.mqtt_prefix + "status/" +
                 intercom.host_name + "/in_menu",
                 "0")
    # SUBSCRIBE TO ROLE
    mqtt_subscribe(intercom.mqtt_prefix + "setup/" +
                   intercom.host_name + "/device_role")
    # SUBSCRIBE TO MIC LEVEL
    if intercom.allow_mic_level_change:
        mqtt_subscribe(intercom.mqtt_prefix + "setup/" +
                       intercom.host_name + "/mic_level")
    # SUBSCRIBE TO TALK
    mqtt_subscribe(intercom.mqtt_prefix + "broadcast/+/talk")
    # SUBSCRIBE TO CHANNEL SETUP
    for i in range(1, intercom.channel_count + 1):
        mqtt_subscribe(intercom.mqtt_prefix + "setup/" +
                       intercom.host_name + "/channel/" + str(i))

def on_disconnect(client: Client,
    userdata: None,
    rc: DisconnectFlags,
    properties: ReasonCode,
    reason_code: Properties
) -> None:
    """MQTT disconnected"""
    sleep(2)
    intercom.system_control = False
    clear_all_displays()
    clear_buttons()
    render_text_lines(
        0,
        [
            intercom.host_name,
            intercom.device_ip,
            "MQTT DISCNTD"
        ]
    )
    client.connected_flag = False


def update_talking_status(message: str, talks_to_me: str) -> None:
    """
    Update the talking status based on the message.

    Args:
        message (str): The message containing the talking status.
        talks_to_me (str): The entity that is talking to me.
    """
    if intercom.user in message:
        intercom.add_talking_to_me(talks_to_me, True)
    else:
        if "not talking" in message:
            if intercom.is_user_talking(talks_to_me):
                intercom.add_talking_to_me(talks_to_me, False)


def clear_display(index: int) -> None:
    """
    Clear the display at the given index.

    Args:
        index (int): The index of the display to clear.
    """
    displays[index].clear_display()


def render_text_display(index: int,
                        text: str,
                        font_path: str,
                        font_size: int,
                        freeze: bool = False,
                        freeze_start: int = None
                        ) -> None:
    current_time = int(time() * 1000)
    if freeze:
        displays[index].update_freeze = True
        if freeze_start != 0 or None:
            displays[index].update_freeze_start = current_time
        else:
            displays[index].update_freeze_start = 0
    displays[index].render_text(text, font_path, font_size)


def render_text_lines(
    display_id: int, 
    text: List[str], 
    font_path: str = None,
    font_size: int = None
) -> None:
    """
    Render text on the display.

    Args:
        index (int): The index of the display.
        text (str): The text to render on the display.
        font_path (str): The path to the font file.
        font_size (int): The size of the font.
        freeze (bool, optional): Whether to freeze the display. 
        Defaults to False.
        freeze_start (int, optional): The start time for freezing. 
        Defaults to None.
    """
    # Assign the default font path if not provided
    if font_path is None:
        font_path = intercom.font_path

    # Assign the default font size if not provided
    if font_size is None:
        font_size = intercom.small_font_size

    displays[display_id].render_text_lines(
        text,
        font_path,
        font_size
    )


def on_message(client: Client, userdata: None, 
               message: MQTTMessage) -> None:
    """
    Handle incoming MQTT messages and respond if needed.

    Args:
        client (Client): The MQTT client instance.
        userdata (Optional[None]): The private user data, not used in this 
                                   function.
        message (MQTTMessage): The message instance containing the topic and 
                               payload.
    """
    if message.topic == (intercom.mqtt_prefix
                         + "setup/"
                         + intercom.host_name
                         + "/device_role"
                         ):
        if str(message.payload.decode()) != "":
            intercom.user = str(message.payload.decode())
            mqtt_publish(intercom.mqtt_prefix
                         + "status/"
                         + intercom.host_name
                         + "/device_role",
                         intercom.user
                         )
            
    if message.topic == (intercom.mqtt_prefix
                         + "setup/"
                         + intercom.host_name
                         + "/mic_level"
                         ):
        if str(message.payload.decode()) != "":
            mic_level = str(message.payload.decode())
            if int(mic_level) >= 0 or int(mic_level) <= 150: 
                intercom.set_mic_level(int(mic_level))
                mqtt_publish(intercom.mqtt_prefix
                             + "status/"
                             + intercom.host_name
                             + "/mic_level",
                             str(intercom.get_mic_level())
                             )

    if (intercom.mqtt_prefix
        + "setup/"
        + intercom.host_name
        + "/channel/"
        ) in message.topic:
        for i in range(intercom.channel_count):
            if message.topic == (intercom.mqtt_prefix
                                 + "setup/"
                                 + intercom.host_name
                                 + "/channel/"
                                 + str(i + 1)
                                 ):
                intercom.talk_to[i] = str(message.payload.decode())
                mqtt_publish(
                    intercom.mqtt_prefix +
                    "status/" +
                    intercom.host_name +
                    "/channel/" +
                    str(i + 1),
                    intercom.talk_to[i]
                )

    if fnmatch.fnmatch(message.topic,
                       intercom.mqtt_prefix
                       + "broadcast/*/talk"
                       ):
        splitted_topic = message.topic.split('/')
        talks_to_me = splitted_topic[len(splitted_topic) - 2]
        if ',' in str(message.payload.decode()):
            # User is talking to many
            splitted_message = str(message.payload.decode()).split(',')
            for user in splitted_message:
                update_talking_status(user, talks_to_me)
        else:
            # User is only talking to me
            update_talking_status(str(message.payload.decode()), talks_to_me)


def publish_talking_to() -> None:
    """
    Publish the current talking status to MQTT.
    """
    talking_to = ""
    # Clear encoder lock
    buttons[intercom.channel_count].is_locked = False
    for i in buttons:
        if (buttons[i].is_locked
                or buttons[i].is_pressed
                and i <= (intercom.channel_count - 1)
                ):
            if talking_to:
                talking_to += ","
            talking_to += intercom.talk_to[i]

    if talking_to == "":
        mqtt_publish(intercom.mqtt_prefix + "broadcast/" +
                     intercom.user.lower() + "/talk", "not talking")
        intercom.published_talk_to = "not talking"
    else:
        if talking_to != intercom.published_talk_to:
            mqtt_publish(intercom.mqtt_prefix + "broadcast/" +
                         intercom.user.lower() + "/talk", talking_to)
            intercom.published_talk_to = talking_to


def show_menu(main: int, sub: int, active: int) -> None:
    """
    Display the menu on the screen.

    Args:
        main (int): The main menu index.
        sub (int): The sub menu index.
        active (int): The currently active menu item.
    """
    max_lines = displays[0].get_max_text_lines(font_path=intercom.font_path,
                                           font_size=intercom.small_font_size)
    lines = []
    total_lines = len(menu[main])

    if total_lines <= max_lines:
        lines = [menu[main][i]["name"] for i in range(total_lines)]
        start = 0
    else:
        # Make sure the active line is always within the displayed lines
        if active < max_lines // 2:
            start = 0
        elif active > total_lines - (max_lines // 2):
            start = total_lines - max_lines
        else:
            start = active - (max_lines // 2)

        end = start + max_lines
        lines = [menu[main][i]["name"] for i in range(start, end)]

    displays[0].update_freeze = True
    displays[0].update_freeze_start = 0
    displays[0].clear_display()
    displays[0].update_menu(
        lines=lines,
        active_line=active - start,
        max_lines=max_lines,
        font_path=intercom.font_path,
        font_size=intercom.small_font_size
    )


def hide_menu() -> None:
    """
    Hide the menu and disable update freeze.
    """
    intercom.in_menu = False
    displays[0].update_freeze = False
    mqtt_publish(intercom.mqtt_prefix
                 + "status/"
                 + intercom.host_name
                 + "/in_menu",
                 "0"
                 )
    


def button_long_press_callback(button: IntercomButton) -> None:
    """
    Callback function for handling long press on a button.

    Args:
        button (IntercomButton): The button that was long pressed.
    """
    intercom.last_interaction_time = int(time() * 1000)
    # Only listen for long press on button 2 to enter menu mode
    if button.num == 2 and not intercom.in_menu:
        intercom.in_menu = True
        intercom.menu_main = 0
        intercom.menu_sub = 0
        show_menu(intercom.menu_main, intercom.menu_sub, 0)
        mqtt_publish(intercom.mqtt_prefix
                     + "status/"
                     + intercom.host_name
                     + "/in_menu",
                     "1"
                     )
        # print("In menu mode")


def menu_logic(main: int, sub: int):
    """
    Handle the logic for displaying and interacting with the menu.

    Args:
        main (int): The main menu index.
        sub (int): The sub menu index.
    """
    global menu

    def show_menu_and_set_intercom(menu_main, menu_sub):
        show_menu(
            menu_main["main"],
            menu_main["sub"],
            menu_main["active"]
        )
        intercom.menu_main = menu_main["main"]
        intercom.menu_sub = menu_main["sub"]

    if main == 0:
        # Main menu
        if sub == 0:
            hide_menu()
        elif sub == 1:
            # Enter lock menu
            for i in range(intercom.channel_count):
                menu[1][i + 1]["name"] = (
                    f"LOCK {i + 1} "
                    f"{'ON' if intercom.lock_buttons[i] else 'OFF'}"
                )
            show_menu_and_set_intercom(menu[0][1], menu[0][1])
        elif sub == 2:
            # Enter Mic Level menu
            show_menu_and_set_intercom(menu[0][2], menu[0][2])
        elif sub == 3:
            # Enter Shut down menu
            show_menu_and_set_intercom(menu[0][3], menu[0][3])
    elif main == 1:
        # Button lock menu
        if sub == 0:
            show_menu_and_set_intercom(menu[1][0], menu[1][0])
        elif 1 <= sub <= intercom.channel_count:
            index = sub - 1
            intercom.lock_buttons[index] = not intercom.lock_buttons[index]
            menu[1][sub]["name"] = (
                f"LOCK {sub} "
                f"{'ON' if intercom.lock_buttons[index] else 'OFF'}"
            )
            show_menu_and_set_intercom(menu[1][sub], menu[1][sub])
    elif main == 2:
        # Mic level menu
        if sub == 0:
            show_menu_and_set_intercom(menu[2][0], menu[2][0])
        elif sub == 1:
            mic_level = intercom.get_mic_level()
            render_text_display(
                index=0,
                text=f"MIC: {mic_level}%",
                font_path=intercom.font_path,
                font_size=intercom.small_font_size,
                freeze=True,
                freeze_start=0
            )
    elif main == 3:
        # Shutdown menu
        if sub == 0:
            show_menu_and_set_intercom(menu[3][0], menu[3][0])
        elif sub == 1:
            intercom.system_active = False
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

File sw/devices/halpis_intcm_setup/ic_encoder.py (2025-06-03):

# This module is part of the HALPIS Intercom project
# Copyright (c) 2024, Niclas Hallgren
# All rights reserved.
#
# This source code is licensed under the MIT license found in the
# LICENSE file in the root directory of this source tree.

import RPi.GPIO as GPIO
import logging
from dataclasses import dataclass, field

# Set the GPIO mode to use the physical pin numbering
GPIO.setmode(GPIO.BOARD)


@dataclass
class IntercomEncoder:
    """
    Handle rotary encoder input using GPIO on Raspberry Pi.
    
    Attributes:
        leftPin (int): GPIO pin connected to the left signal of the encoder.
        rightPin (int): GPIO pin connected to the right signal of the encoder.
        callback (function): Function to call when the encoder value changes.
        value (int): The current value of the encoder.
        state (str): The current state of the encoder's signals.
        direction (str): The direction of the last detected movement 
        ("R" or "L").
    """
    leftPin: int
    rightPin: int
    callback: any = None  # No strict typing for callback, allows any callable
    value: int = 0
    state: str = field(default="00", init=False)
    direction: str = field(default=None, init=False)

    logger: logging.Logger = field(init=False, repr=False)

    def __post_init__(self):
        """
        Initialize the GPIO pins for the encoder and set up event detection
        for both pins. Log any errors encountered during setup.
        """
        self.logger = logging.getLogger(__name__)
        try:
            # Setup the GPIO pins with pull-up resistors and event detection
            self.logger.debug(
                f"Setting up GPIO pins: leftPin={self.leftPin}, "
                f"rightPin={self.rightPin}"
            )
            GPIO.setup(self.leftPin, GPIO.IN, pull_up_down=GPIO.PUD_DOWN)
            GPIO.setup(self.rightPin, GPIO.IN, pull_up_down=GPIO.PUD_DOWN)

            # Add event detection for both left and right pins
            GPIO.add_event_detect(
                self.leftPin, GPIO.BOTH, callback=self.transitionOccurred
            )
            GPIO.add_event_detect(
                self.rightPin, GPIO.BOTH, callback=self.transitionOccurred
            )

            # Read the initial state of the encoder's pins
            initial_p1 = GPIO.input(self.leftPin)
            initial_p2 = GPIO.input(self.rightPin)
            self.state = f"{initial_p1}{initial_p2}"
            self.logger.debug(f"Initial encoder state: {self.state}")

            self.logger.debug("GPIO pins set up successfully")

        except ValueError as e:
            # Handle invalid GPIO pin numbers
            self.logger.error(f"Invalid GPIO pin numbers: {e}")
            raise

        except RuntimeError as e:
            # Handle issues related to GPIO setup, such as 
            # lack of initialization
            self.logger.error(f"GPIO setup error: {e}")
            raise

        except Exception as e:
            # Catch-all for any other exceptions during setup
            self.logger.error(f"Unexpected error during GPIO setup: {e}")
            raise

    def getValue(self):
        """
        Retrieve the current value of the encoder and log the retrieval.
        
        Returns:
            int: The current value of the encoder.
        """
        self.logger.debug(f"Getting value: {self.value}")
        return self.value

    def transitionOccurred(self, _):
        """
        Called when a GPIO pin state change is detected. Updates the encoder's
        state and checks for valid transitions to determine the direction of
        rotation. Logs detected transitions and updates the value accordingly.
        
        Args:
            _ (int): Ignored argument, required by GPIO callback interface.
        """
        # Read the current state of the left and right encoder pins
        p1 = GPIO.input(self.leftPin)
        p2 = GPIO.input(self.rightPin)
        newState = f"{p1}{p2}"

        self.logger.debug(
            f"Transition occurred: newState={newState}, oldState={self.state}"
        )

        # Define valid transitions for right (clockwise) 
        # and left (counterclockwise)
        valid_right = [
            ("00", "01"), ("01", "11"), ("11", "10"), ("10", "00")
        ]
        valid_left = [
            ("00", "10"), ("10", "11"), ("11", "01"), ("01", "00")
        ]

        if (self.state, newState) in valid_right:
            # Right (clockwise) rotation detected
            self.direction = "R"
            self.logger.debug("Detected Right movement")
            if newState == "00":
                # Full right movement completed
                self.logger.debug("Right movement complete")
                self.updateValue(1)

        elif (self.state, newState) in valid_left:
            # Left (counterclockwise) rotation detected
            self.direction = "L"
            self.logger.debug("Detected Left movement")
            if newState == "00":
                # Full left movement completed
                self.logger.debug("Left movement complete")
                self.updateValue(-1)

        else:
            # Invalid or noisy transition, ignore it
            self.logger.debug(
                f"Invalid transition: {self.state} -> {newState}, ignoring"
            )

        # Update the encoder's state
        self.state = newState

    def updateValue(self, delta):
        """
        Update the encoder's value by the specified delta and invoke the 
        callback if provided. Logs the value update and any errors in 
        the callback execution.
        
        Args:
            delta (int): The change to apply to the encoder's value.
        """
        # Update the value and log the change
        self.logger.debug(
            f"Updating value: current={self.value}, delta={delta}"
        )
        self.value += delta
        self.logger.debug(f"New value: {self.value}")

        # Call the callback function if provided
        if self.callback:
            self.logger.debug(
                f"Calling callback with value={self.value} "
                f"and direction={self.direction}"
            )
            try:
                self.callback(self.value, self.direction)
            except Exception as e:
                # Log any exceptions raised during callback execution
                self.logger.warning(f"Error during callback: {e}")

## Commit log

2025-06-03 Updated to stl versions
2025-06-04 Fixed a typo and a bug in last_interaction_time
    [ic_basestation.py]
2025-06-04 Fixed a bug in last_interaction_time
    [ic_beltpack.py]
